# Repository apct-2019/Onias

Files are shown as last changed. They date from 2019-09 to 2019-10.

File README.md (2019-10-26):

# Layout e componentes de características distribuídas 

O Layout da placa diz respeito ao posicionamento e dimensão das trilhas e componentes que compõe o circuito. É a manifestação física do esquemático da placa.

Para este projeto, existem os seguintes pre-requisitos:
- Conector MicroRF e cabo para SMA
- Conversor DC/DC para células de lítio com saída para 7,4V 4A
- Conector Dados com SPI, I2C, GPIO (2 I/O)

Por se tratar de uma placa que deve operar com sinais de alta frequência, alguns cuidados adicionais devem ser tomados:

- Impedância das trilhas deve ser controlada
- A frequência do ripple dos níveis DC não pode causar interferência nos sinais AC

Dados esses dois cuidados, algumas conclusões podem ser tiradas: 

- Trabalharemos com impedâncias controladas o mais próximo possível de 50 ohms;
- Cada componente do circuito deve ter seu próprio conversor DC/DC, para que não causem interferência entre si;
- O circuito de conversão DC/DC deve ser apropriado para circuitos de RF

Abaixo um vídeo exemplificando como será a estratégia de desenvolvimento das placas:

X-Microwave's Modular RF System (https://www.youtube.com/watch?v=o7zYtF5dE3c "X-Microwave's Modular RF System")

Pode-se observar a modularidade de cada parte do circuito, podendo fazê-lo a medida que os componentes vão sendo selecionados.

## Parâmetros das placas e conectores:

Características da placa:

- 4 camadas;
- 3 dielétricos;
- espessura de condutores: 0.14mm;
- espessura dos dielétricos: 0.635mm;
- espessura total: 0.795mm

Layer Stack Manager:

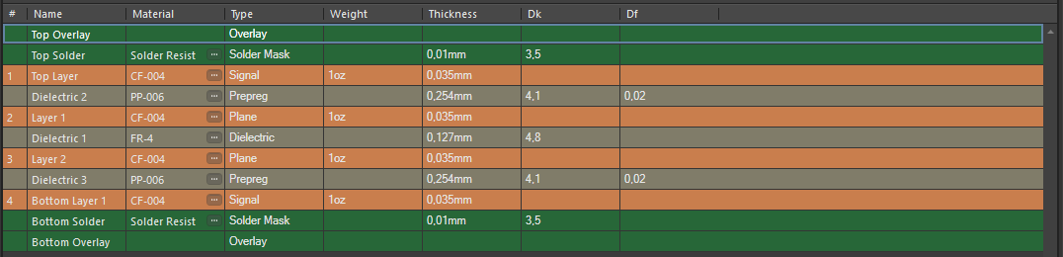
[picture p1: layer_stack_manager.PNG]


Conectores:

Os conectores usados são groud-signal-ground (gsg) Jumpers. São feitos de um pequeno pedaço de material de poliamida com traços de cobre desenhados para terem impedância de 50 ohms na direção do sinal. Para fixação, o conector é disposto entre duas placas e duas âncoras de forma que fica fixo em cada placa, assegurando conexão. A conexão foi testada com ótimos resultados com frequências até 67GHz, ou seja, para nossa aplicação o conector é válido. 

Quanto aos seus parâmetros s, duas placas conectadas por um gsg Jumper se comportam como uma única linha de transmissão de mesmo tamanho.

Seu Serial number é: XM-GSGJ-01

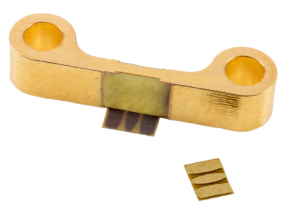
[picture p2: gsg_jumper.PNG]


## Blocos de circuito:

- atenuador: HMC542     - layout feito
- LNA: TQP3M9019        - layout feito
- Gain Block: MAR-6+    - layout feito
- Mixer: ADE-12MH       - layout feito 
- LO: Si4464            - layout feito
- XTAL: 26MHz           - layout feito
- Chave RF: ADG904BCPZ  - layout feito
- Filtro: LTM455/450    - layout feito
- Conector: SMA         - layout feito
- Circuito Step-Up	- layout feitos

## Detalhamento dos componentes:

### Atenuador HMC542

Componente foi criado no vault.

Layout e esquemáticos recomendados pelo fabricante: 

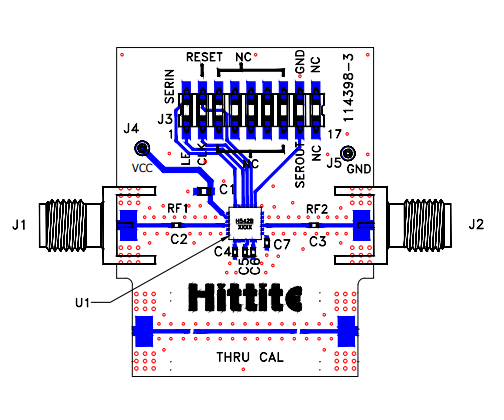
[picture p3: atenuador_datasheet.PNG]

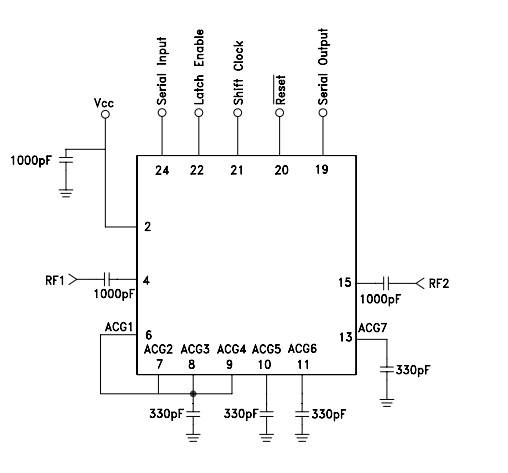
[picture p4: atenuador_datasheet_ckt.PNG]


Esquemático do atenuador - foram utilizados 470pF ao invés de 330pF por simplicidade no esquemático (o capacitor de 330pF não consta no vault):

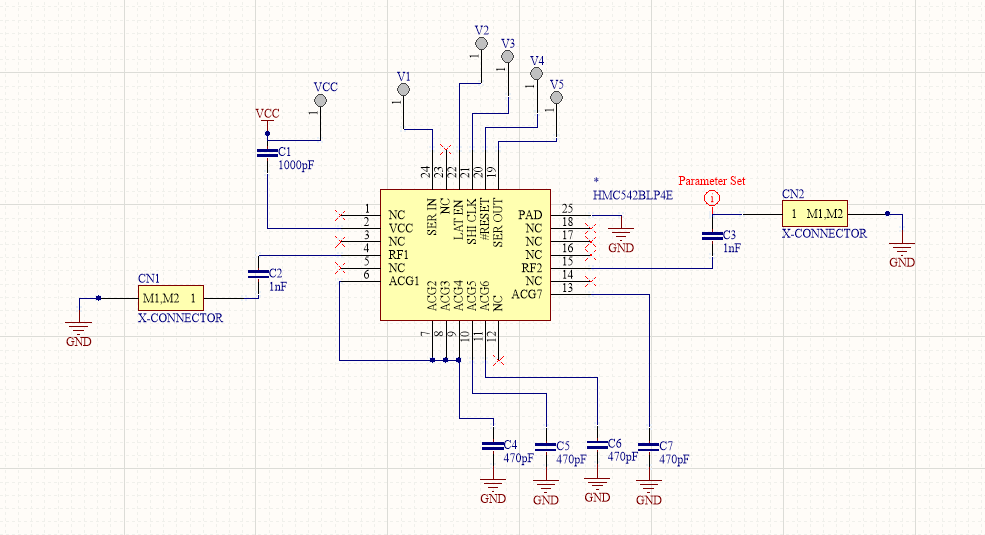
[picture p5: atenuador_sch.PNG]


Foi escolhido um conector grande demais para os sinais lógicos e VCC. Uma outra proposta é usar test points e soldar fios individuais. Layout da placa:

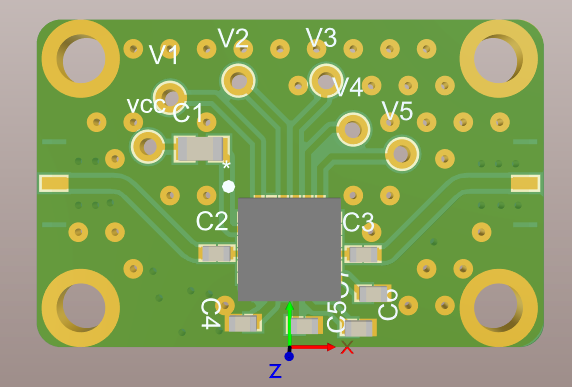
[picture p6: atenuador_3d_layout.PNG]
 

update:
trilhas da pcb em 2d:
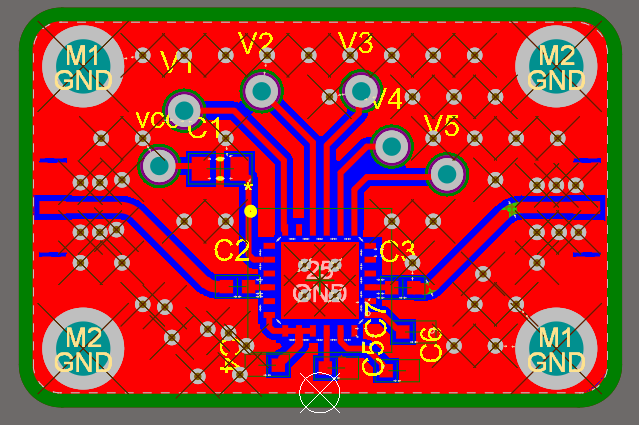
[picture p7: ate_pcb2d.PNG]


### LNA: TQP3M9019

Layout recomendado pelo fabricante:

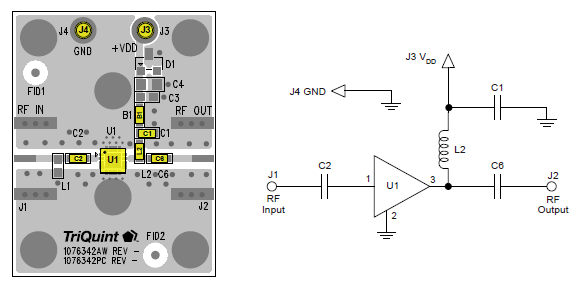
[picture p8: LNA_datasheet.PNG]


Para frequência de operação na faixa 108 a 137 MHz, foram usados os valores 4.7nF e 100nF para os capacitores e 330pH para o indutor
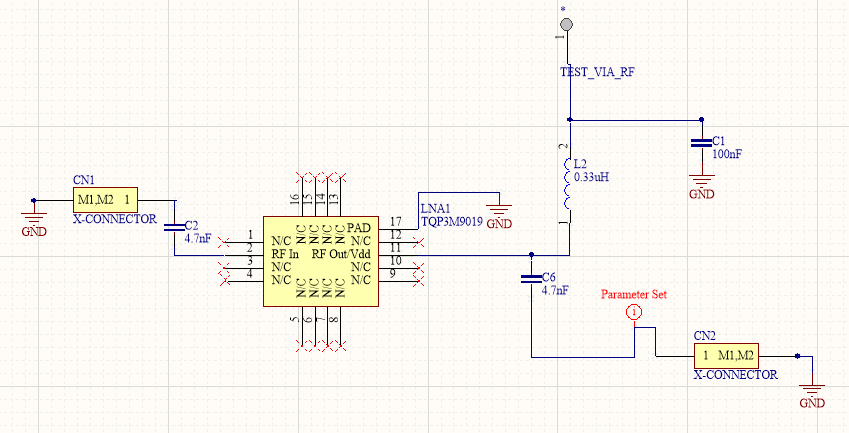
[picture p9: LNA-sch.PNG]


Após o posiciomentos dos componentes, este ficou o layout do módulo do LNA:
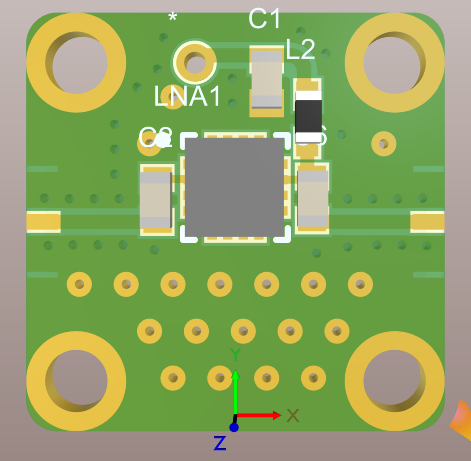
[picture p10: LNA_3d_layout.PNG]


### Gain Block: MAR-6+

Antes era componente LMH6881 (Componente foi criado no vault.)

O MAR-6+ foi criado no vault e foi feito o sch baseado no circuito similar no X-microwave e datasheet do fabricante.

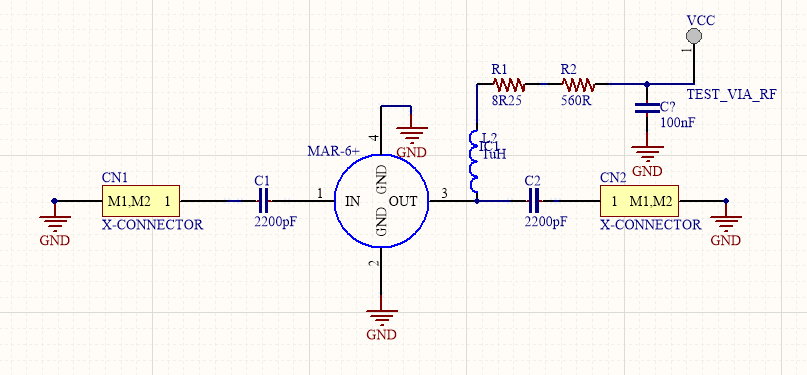
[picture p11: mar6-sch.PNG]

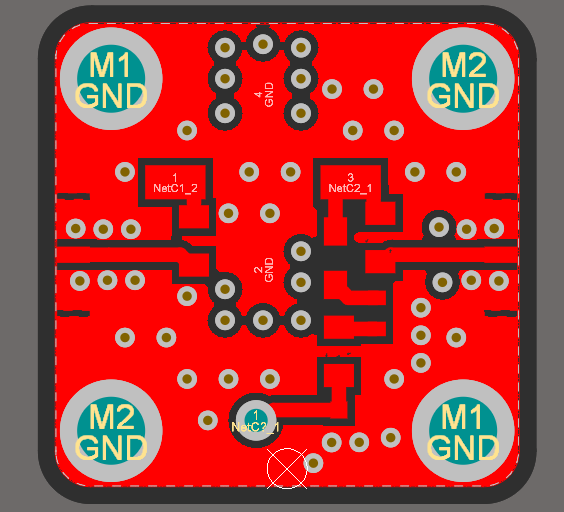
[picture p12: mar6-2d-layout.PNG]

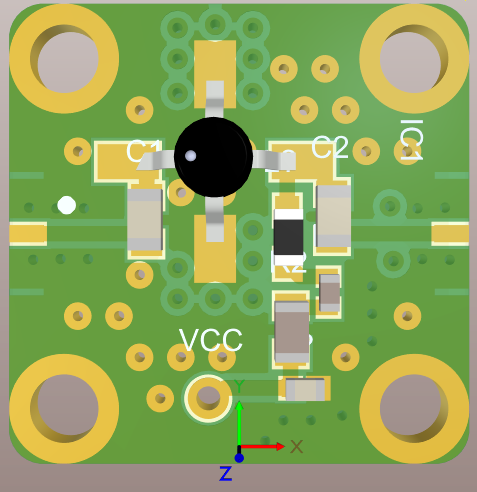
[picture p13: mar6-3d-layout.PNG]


### Mixer: ADE-12MH

O mixer foi dado como exemplo para desenvolvimento das demais placas:

Esquemático utilizado:

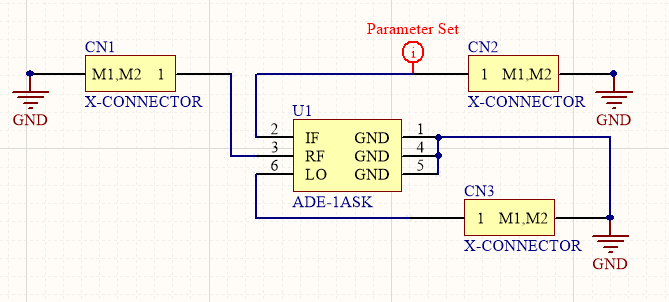
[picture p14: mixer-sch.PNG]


Layout do módulo do Mixer ADE-12MH

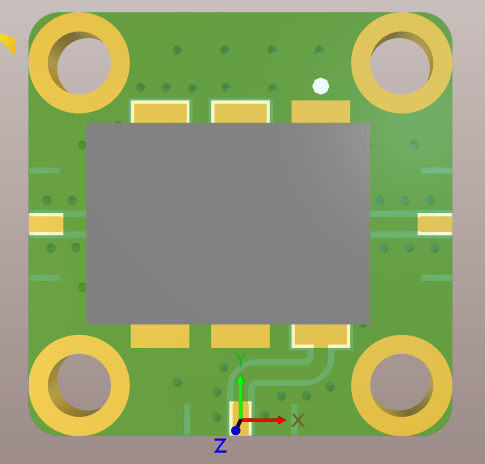
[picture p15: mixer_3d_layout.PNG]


### LO: Si4464

### Chave RF: ADG904BCPZ

Componente foi criado no vault. Componente foi feito o sch baseado no circuito similar no X-microwave e datasheet do fabricante.

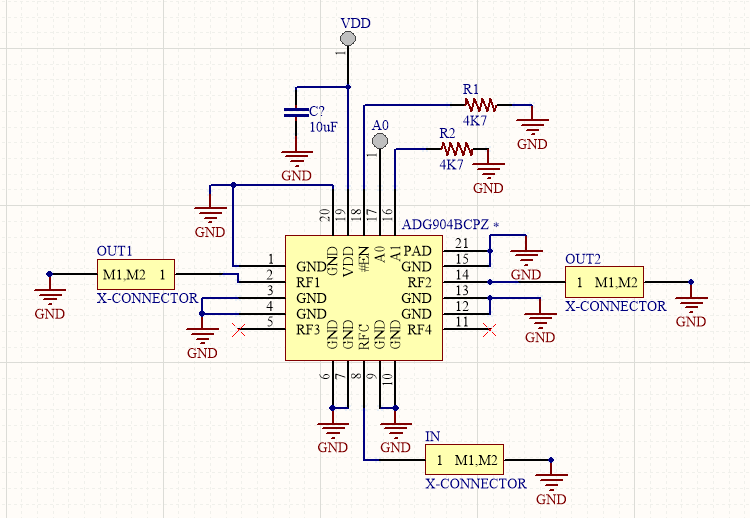
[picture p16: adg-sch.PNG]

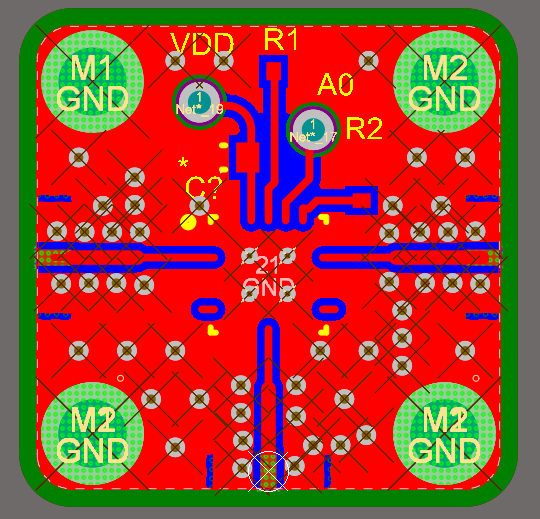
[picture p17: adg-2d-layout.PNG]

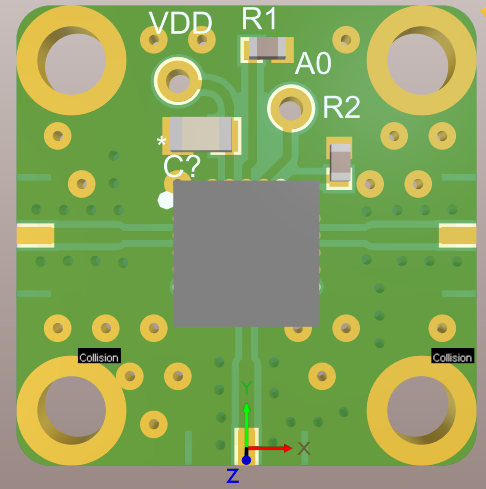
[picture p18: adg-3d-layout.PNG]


### Conector: SMA

Componente usado foi conector SMA.

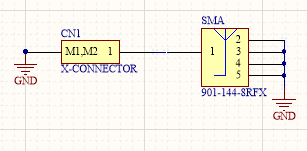
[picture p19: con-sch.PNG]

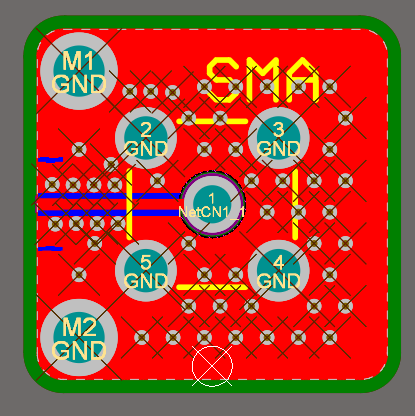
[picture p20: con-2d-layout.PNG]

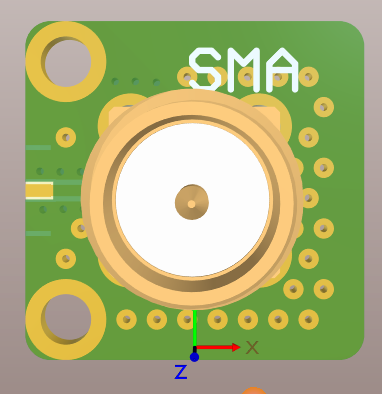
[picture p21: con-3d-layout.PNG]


### Local Oscilator: Si4464 com XTAL 26MHz

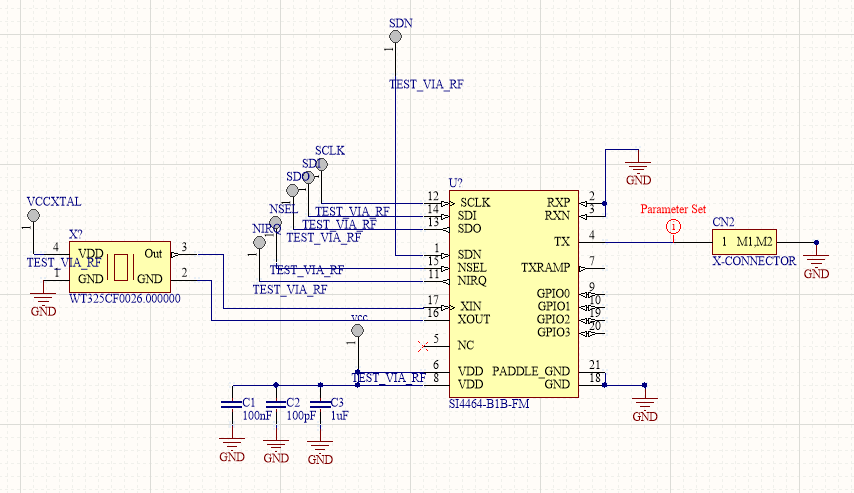
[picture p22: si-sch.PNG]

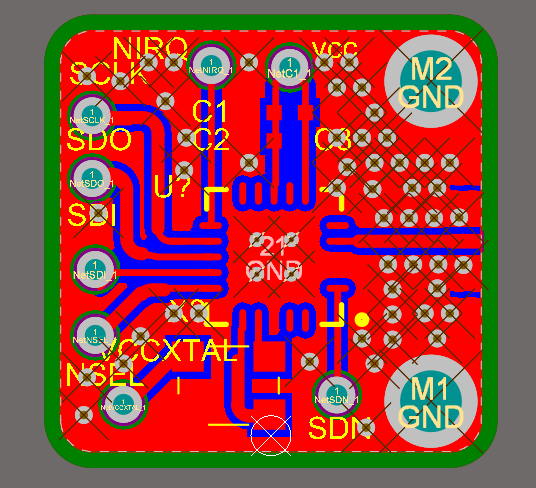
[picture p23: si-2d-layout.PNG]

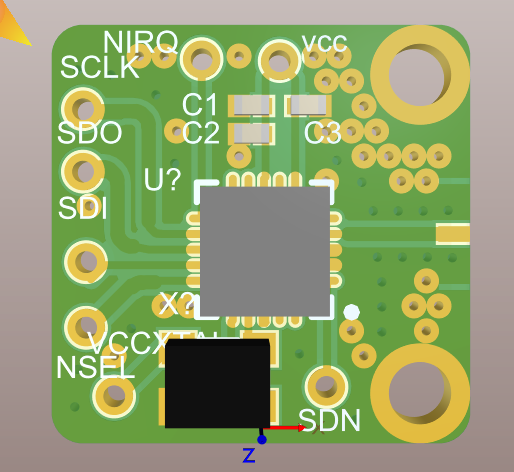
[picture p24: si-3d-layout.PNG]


### Circuito Step-Up: REG113 + LT3042

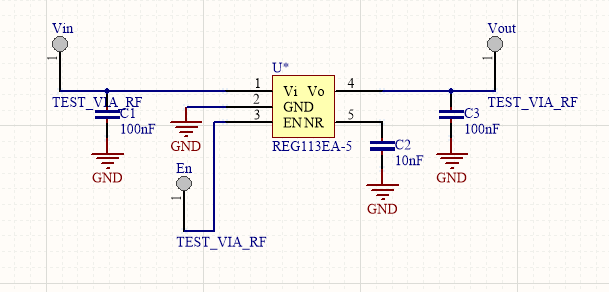
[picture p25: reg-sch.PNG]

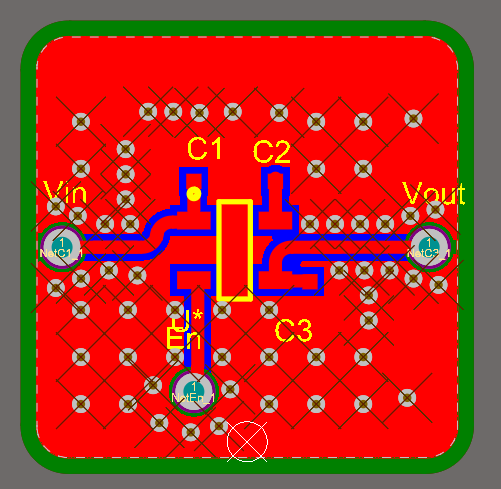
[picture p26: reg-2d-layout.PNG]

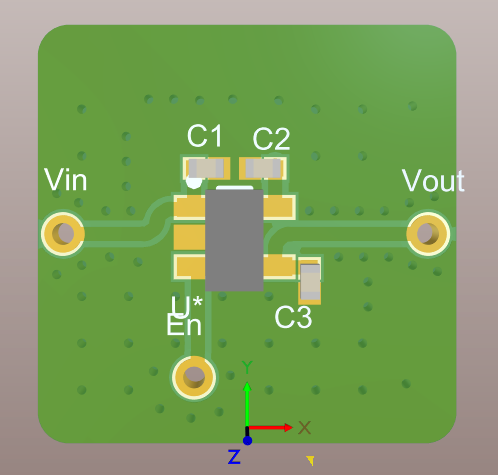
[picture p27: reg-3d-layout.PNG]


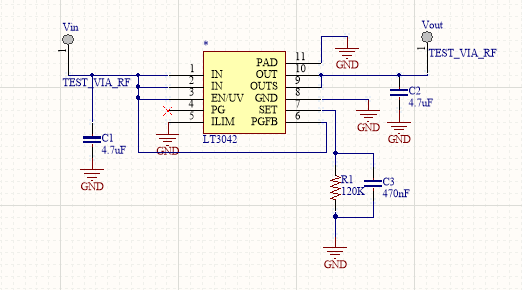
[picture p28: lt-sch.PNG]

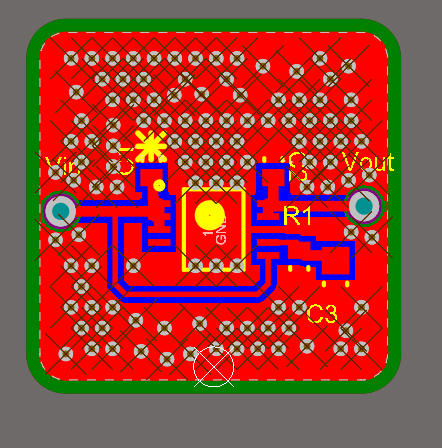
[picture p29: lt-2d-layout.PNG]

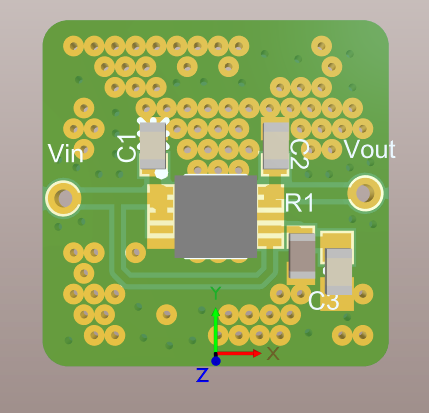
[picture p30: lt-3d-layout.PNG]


### Filtro passivo: LTM455

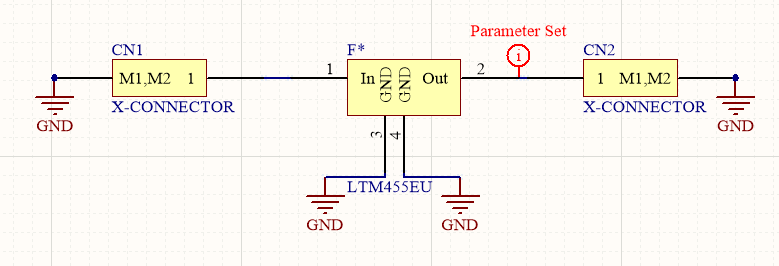
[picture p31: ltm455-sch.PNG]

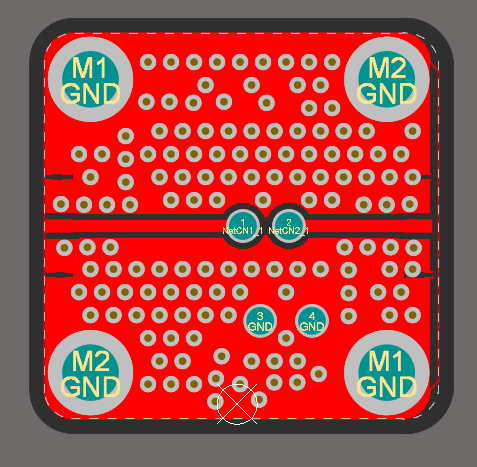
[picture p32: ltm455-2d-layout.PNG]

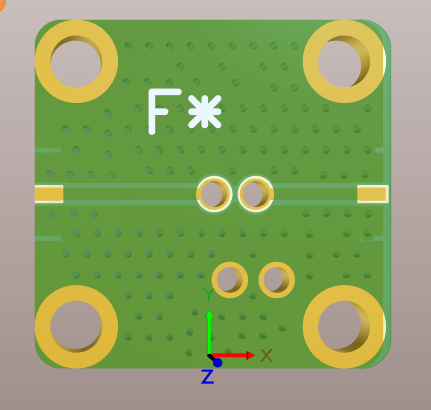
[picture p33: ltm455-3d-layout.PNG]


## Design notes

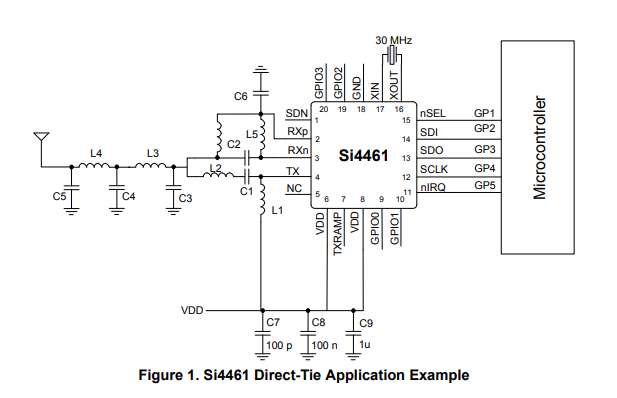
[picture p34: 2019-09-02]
LO_datasheet_ckt.PNG

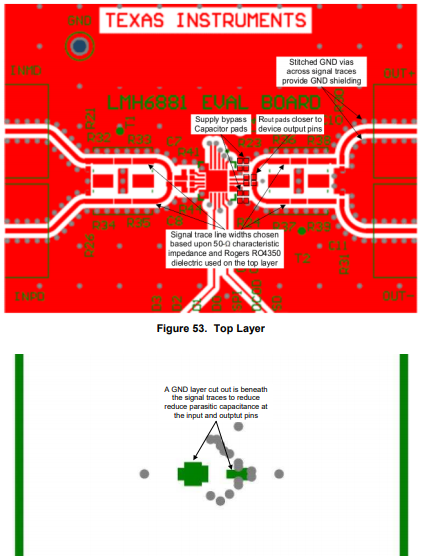
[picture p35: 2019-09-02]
GainBlock_datasheet.PNG

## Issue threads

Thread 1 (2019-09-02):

Faltam outros projetos

luizrenault, 2019-09-02:
Faltam layout para outros projetos.
Deverá haver um módulo para cada bloco do receptor.

Deverão ser especificados os parâmetros das linhas de transmissão, stackup, tipo de LT utilizado e dimensões.

Especificação e características dos conectores.

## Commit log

2019-09-02 adds LNA layout, sch and images
    [LNA_RF_Board.PrjPcb, LNA_RF_Sch.SchDoc]
2019-09-02 adds mixer sch and layout
    [X-4x4-ADE-12MH+.PcbDoc, X-ADE-12MH+.SchDoc]
2019-09-02 adiciona sch e pcb do atenuador
    [Ate_RF_Board.PcbDoc, Ate_RF_Sch.SchDoc]
2019-10-02 adds several schs and layouts
    [ADG904_pcb.PcbDoc, ADG904_sch.SchDoc, Ate_RF_Board.PcbDoc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]
2019-10-23 adds more layouts
    [REG113-25_pcb.PcbDoc, REG113-25_sch.SchDoc, REG113-33_pcb.PcbDoc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]
2019-10-26 adds ltm255 filter sch and layout
    [LTM455_pcb.PcbDoc, LTM455_sch.SchDoc]
